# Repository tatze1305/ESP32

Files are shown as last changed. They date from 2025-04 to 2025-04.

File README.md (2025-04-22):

# ESP32 Entwicklerboard — KiCad Projekt 🕸️

Dies ist das Open-Source-Projekt **Spinne Werkstatt**, erstellt mit [KiCad](https://kicad.org/).  
Es handelt sich um ein Platinen-Design, das frei zur Verfügung steht und für eigene Zwecke verwendet, modifiziert oder weitergegeben werden kann.

---

## 🔧 Inhalt

- `esp32.kicad_sch` — Schaltplan-Datei  
- `esp32.kicad_pcb` — Platinenlayout  
- `gerber/` — Produktionsdaten (Gerber Files)  
- `PDF/` — PDF-Exports für Dokumentation  
- `README.md` — Diese Datei  
- `LICENSE` — Lizenzinformationen (MIT License)

---

## 🚀 Verwendung

Du kannst dieses Projekt:
- verwenden,
- verändern,
- kommerziell oder privat vertreiben,
- als Basis für eigene Entwicklungen nutzen.

Bitte beachte die Lizenzbedingungen in der `LICENSE`-Datei.

---

## 🧑‍💻 Mitmachen

Pull-Requests, Verbesserungen, Bug-Reports oder Ideen sind willkommen!  
Einfach ein Issue öffnen oder forken und loslegen.

---

## 📄 Lizenz

Dieses Projekt steht unter der [MIT License](LICENSE).

> Frei zur Nutzung, Veränderung und Verbreitung — mit Namensnennung.

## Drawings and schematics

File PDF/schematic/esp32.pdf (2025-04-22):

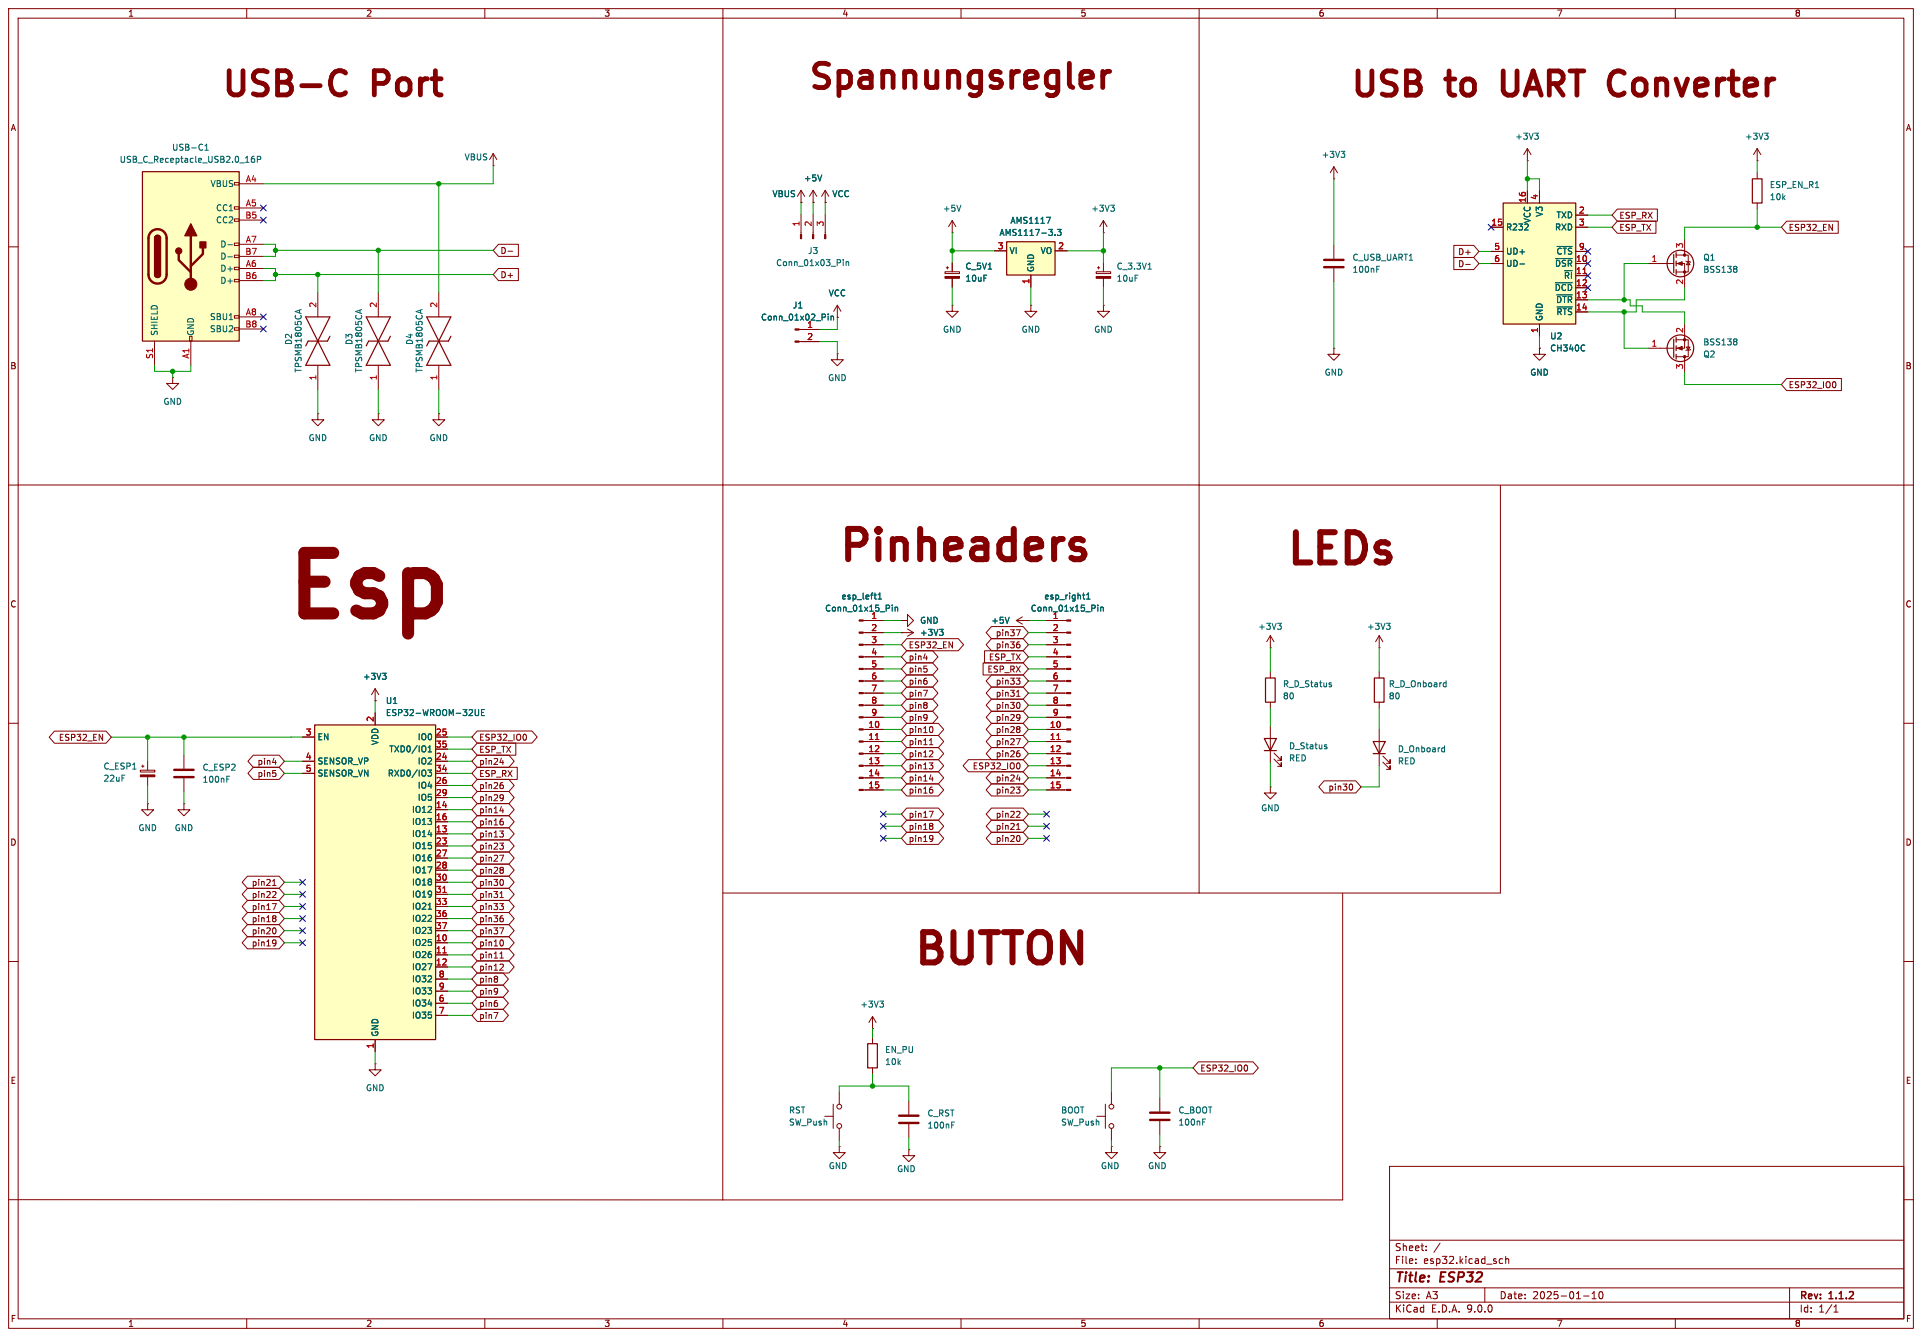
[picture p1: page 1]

1 2 D2 TPSMB1805CA GND SHIELD S1 GND A1 VBUS A4 CC1 A5 CC2 B5 D- A7 D- B7 D+ A6 D+ B6 SBU1 A8 SBU2 B8 USB-C1 USB_C_Receptacle_USB2.0_16P GND

1 TXD 2 RXD 3 ~{CTS}9 ~{DSR} 10 ~{RI} 11 ~{DCD} 12 ~{DTR} 13 ~{RTS} 14 U2 CH340C

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

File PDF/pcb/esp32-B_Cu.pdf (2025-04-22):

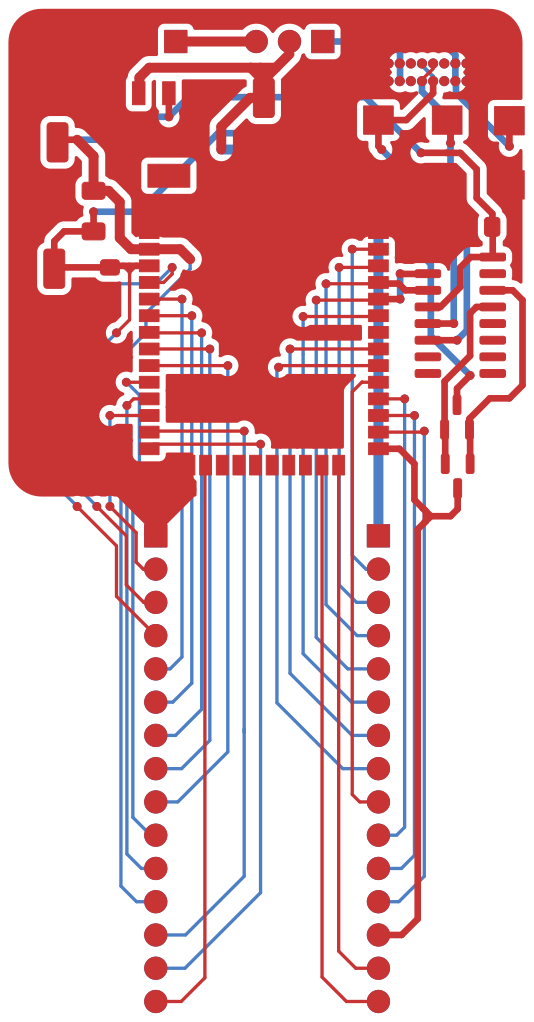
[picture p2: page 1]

Id: 2/4 Title: File: esp32.kicad_pcb Sheet:

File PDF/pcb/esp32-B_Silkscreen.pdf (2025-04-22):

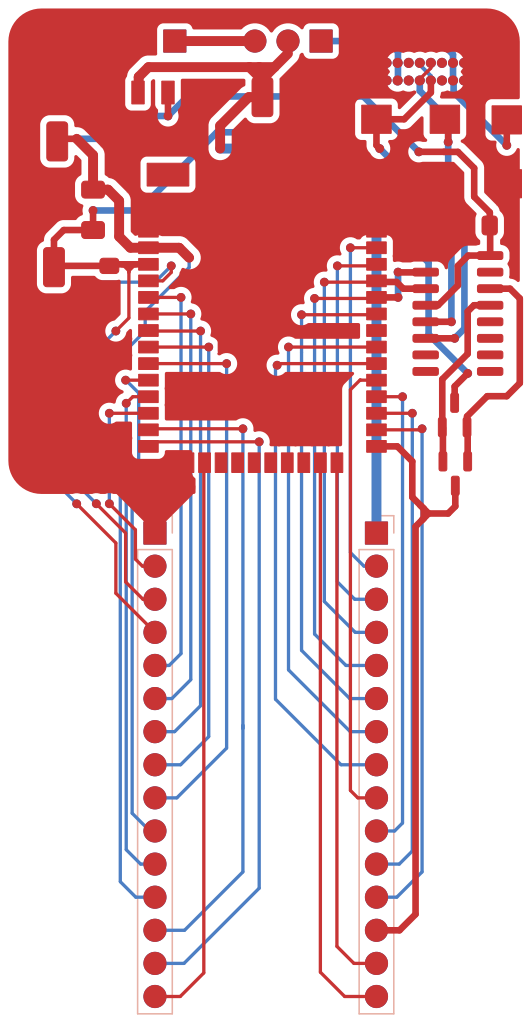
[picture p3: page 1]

Id: 4/4 Title: File: esp32.kicad_pcb Sheet:

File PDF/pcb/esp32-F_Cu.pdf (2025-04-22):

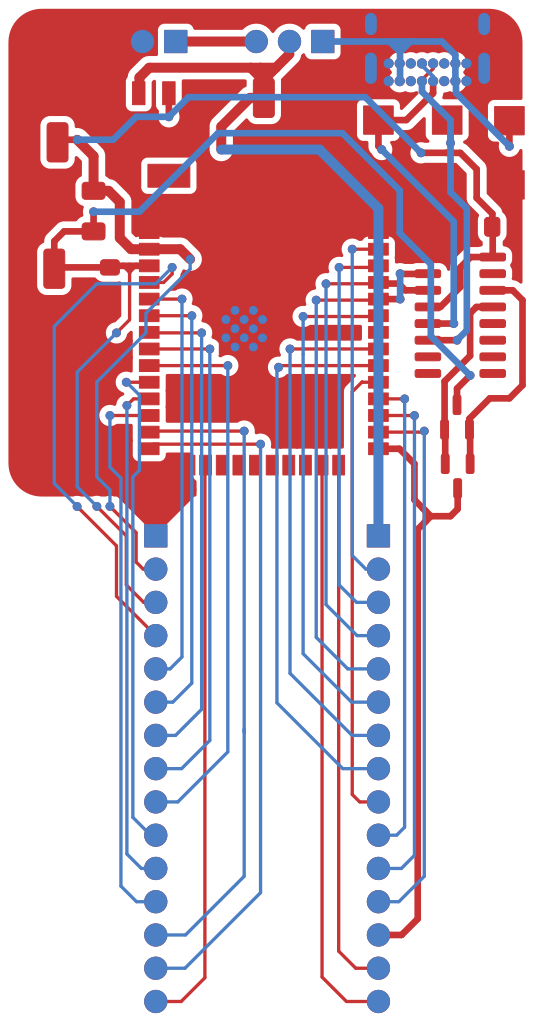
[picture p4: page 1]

Id: 1/4 Title: File: esp32.kicad_pcb Sheet:

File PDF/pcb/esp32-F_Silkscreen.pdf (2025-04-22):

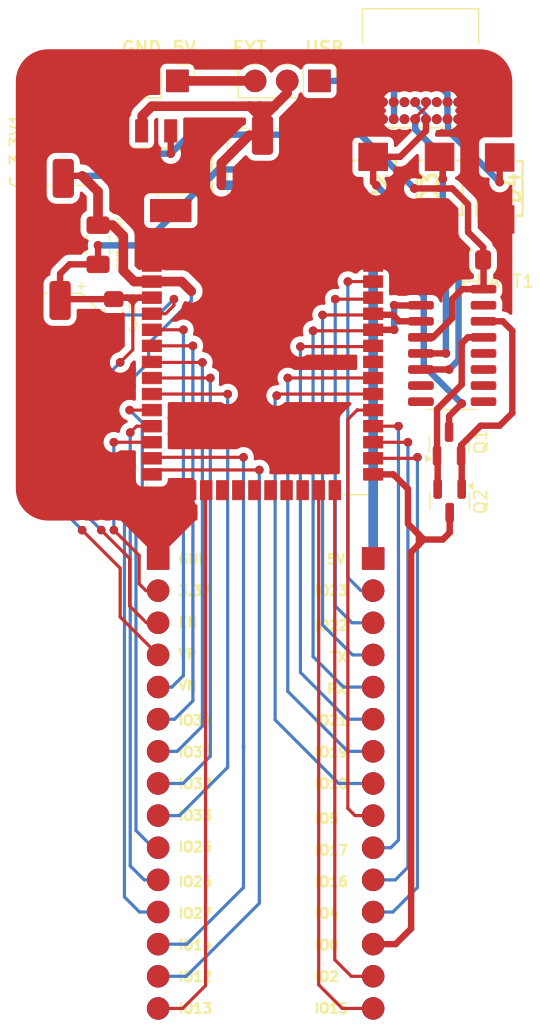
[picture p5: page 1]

Id: 3/4 Title: File: esp32.kicad_pcb Sheet:

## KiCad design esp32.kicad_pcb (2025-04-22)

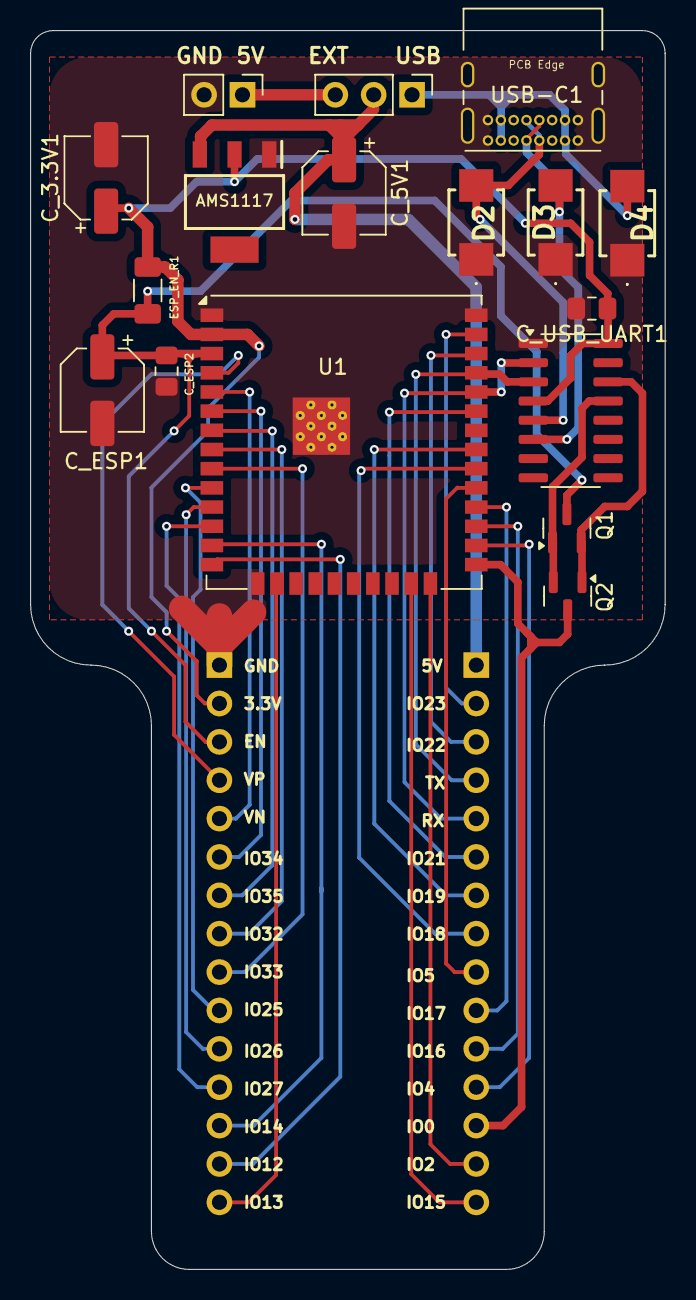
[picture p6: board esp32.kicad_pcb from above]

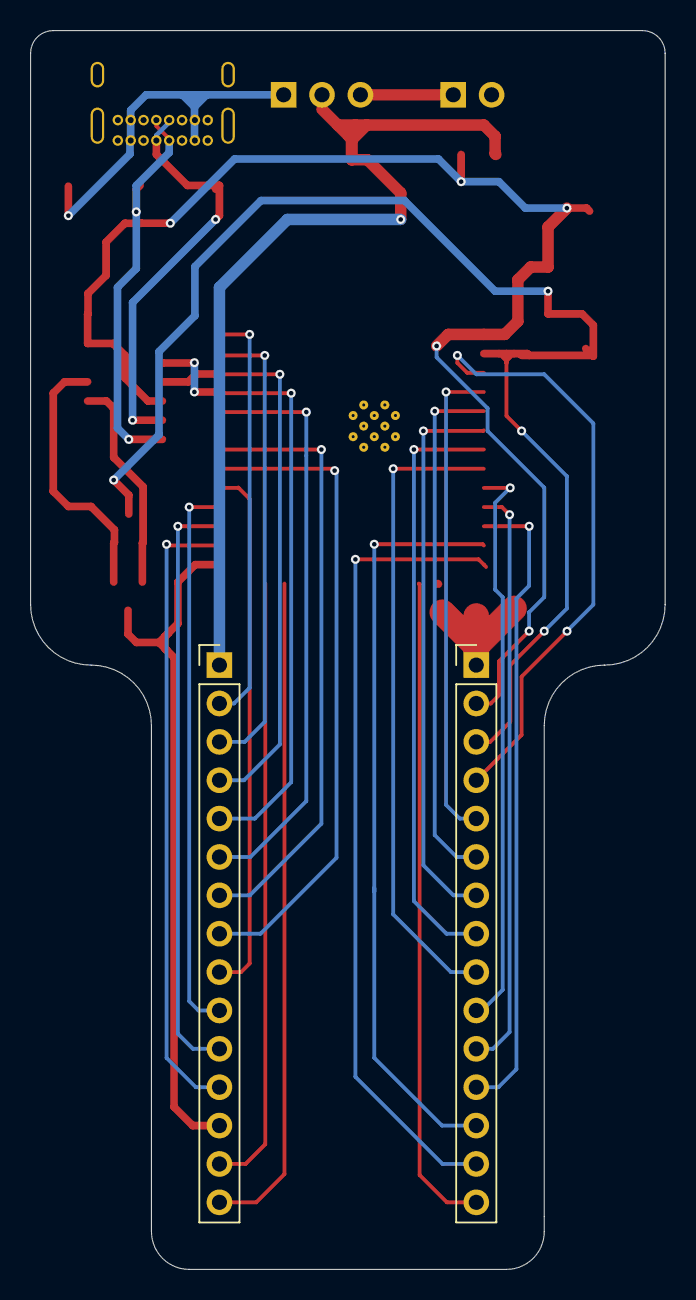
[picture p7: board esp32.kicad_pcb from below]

Board: 2 copper layers, 42.0 x 82.0 mm, 19 parts (2 on the bottom side), 36 nets.

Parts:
AMS1117: AMS1117-3.3; SOT230P700X180-4N
C_3.3V1, C_5V1: 1uF; CP_Elec_5x5.4
C_ESP1: 22uF; CP_Elec_5x5.4
C_ESP2: 100nF; C_0805_2012Metric_Pad1.18x1.45mm_HandSolder
C_USB_UART1: 100nF; C_0805_2012Metric_Pad1.18x1.45mm_HandSolder
D2, D3, D4: TPSMB1805CA
ESP_EN_R1: 10k; R_1206_3216Metric_Pad1.30x1.75mm_HandSolder
J1: Conn_01x02_Pin; PinHeader_1x02_P2.54mm_Vertical
J3: Conn_01x03_Pin; PinHeader_1x03_P2.54mm_Vertical
Q1, Q2: BSS138; SOT-23
U1: ESP32-WROOM-32UE
U2: CH340C; SOIC-16_3.9x9.9mm_P1.27mm
USB-C1: USB_C_Receptacle_USB2.0_16P; USB_C_Receptacle_GCT_USB4085
esp_left1: Conn_01x15_Pin; PinHeader_1x15_P2.54mm_Vertical
esp_right1: Conn_01x15_Pin; PinHeader_1x15_P2.54mm_Vertical

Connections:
+3V3: AMS1117.2 (VO), C_3.3V1.1, C_USB_UART1.1, ESP_EN_R1.1, U1.2 (VDD), U2.4 (V3), U2.16 (VCC), esp_left1.2
+5V: AMS1117.3 (VI), C_5V1.1, J3.2, esp_right1.1
D+: D2.2, U2.5 (UD+), USB-C1.A6 (D+), USB-C1.B6 (D+)
D-: D3.2, U2.6 (UD-), USB-C1.A7 (D-), USB-C1.B7 (D-)
ESP32_EN: C_ESP1.1, C_ESP2.1, ESP_EN_R1.2, Q1.3 (D), U1.3 (EN), esp_left1.3
ESP32_IO0: Q2.3 (D), U1.25 (IO0), esp_right1.13
ESP_RX: U1.34 (RXD0/IO3), U2.2 (TXD), esp_right1.5
ESP_TX: U1.35 (TXD0/IO1), U2.3 (RXD), esp_right1.4
GND: AMS1117.1 (GND), C_3.3V1.2, C_5V1.2, C_ESP1.2, C_ESP2.2, C_USB_UART1.2, D2.1, D3.1, D4.1, J1.2, U1.1 (GND), U1.15 (GND), U1.38 (GND), U1.39 (GND), U2.1 (GND), USB-C1.A1 (GND), USB-C1.A12 (GND), USB-C1.B1 (GND), USB-C1.B12 (GND), USB-C1.S1 (SHIELD), esp_left1.1
unnamed: Q1.1 (G), Q2.2 (S), U2.13 (~DTR)
unnamed: Q1.2 (S), Q2.1 (G), U2.14 (~RTS)
VBUS: D4.2, J3.1, USB-C1.A4 (VBUS), USB-C1.A9 (VBUS), USB-C1.B4 (VBUS), USB-C1.B9 (VBUS)
VCC: J1.1, J3.3
pin4: U1.4 (SENSOR_VP), esp_left1.4
pin5: U1.5 (SENSOR_VN), esp_left1.5
pin6: U1.6 (IO34), esp_left1.6
pin7: U1.7 (IO35), esp_left1.7
pin8: U1.8 (IO32), esp_left1.8
pin9: U1.9 (IO33), esp_left1.9
pin10: U1.10 (IO25), esp_left1.10
pin11: U1.11 (IO26), esp_left1.11
pin12: U1.12 (IO27), esp_left1.12
pin13: U1.13 (IO14), esp_left1.13
pin14: U1.14 (IO12), esp_left1.14
pin16: U1.16 (IO13), esp_left1.15
pin23: U1.23 (IO15), esp_right1.15
pin24: U1.24 (IO2), esp_right1.14
pin26: U1.26 (IO4), esp_right1.12
pin27: U1.27 (IO16), esp_right1.11
pin28: U1.28 (IO17), esp_right1.10
pin29: U1.29 (IO5), esp_right1.9
pin30: U1.30 (IO18), esp_right1.8
pin31: U1.31 (IO19), esp_right1.7
pin33: U1.33 (IO21), esp_right1.6
pin36: U1.36 (IO22), esp_right1.3
pin37: U1.37 (IO23), esp_right1.2

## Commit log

2024-12-12 add esp32 wroom
    [Spinne_Werkstatt.csv, Spinne_Werkstatt.kicad_pcb, Spinne_Werkstatt.kicad_sch]
2024-12-12 added esp32 wroom 32UE
    [Spinne_Werkstatt.kicad_sch]
2024-12-13 finished first pcb -- ugly
    [Spinne_Werkstatt.kicad_pcb]
2024-12-30 nearly finished, not perfect but ok
    [Spinne_Werkstatt.kicad_pcb]
2024-12-30 finished, not that bad
    [Spinne_Werkstatt.kicad_pcb]
2024-12-30 removed errors, only esp gnd and usb c port ramaining errors, not fixable
    [Spinne_Werkstatt.kicad_pcb]
2024-12-30 added gerber files
    [Spinne_Werkstatt-B_Cu.gbr, Spinne_Werkstatt-B_Mask.gbr, Spinne_Werkstatt-B_Paste.gbr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]
2024-12-30 added gerber
    [Spinne_Werkstatt-B_Cu.gbl, Spinne_Werkstatt-B_Cu.gbr, Spinne_Werkstatt-B_Mask.gbr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]
2024-12-30 finished gerber issue
    [Spinne_Werkstatt.kicad_pcb]
2024-12-31 improved ground plain -- version 1.1.2
    [Spinne_Werkstatt.kicad_pcb]
2024-12-31 renewed zip
    [Spinne_Werkstatt-B_Cu.gbl, Spinne_Werkstatt-B_Mask.gbs, Spinne_Werkstatt-B_Paste.gbp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]
2024-12-31 added IO Names, improved vias
    [Spinne_Werkstatt-B_Cu.gbl, Spinne_Werkstatt-B_Mask.gbs, Spinne_Werkstatt-B_Paste.gbp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]
2024-12-31 improved clearences around uart capacitor
    [Spinne_Werkstatt.kicad_pcb]
2024-12-31 improved clearence around uart capacitor
    [Spinne_Werkstatt-B_Cu.gbl, Spinne_Werkstatt-B_Mask.gbs, Spinne_Werkstatt-B_Paste.gbp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]
2024-12-31 changed elko footprints, changed voltage regulator footprint
    [Spinne_Werkstatt-B_Cu.gbl, Spinne_Werkstatt-B_Mask.gbs, Spinne_Werkstatt-B_Paste.gbp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]
2024-12-31 finished footprints, all completed -- version 1.1.2
    [Spinne_Werkstatt-B_Cu.gbl, Spinne_Werkstatt-B_Mask.gbs, Spinne_Werkstatt-B_Paste.gbp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]
2025-01-01 placed names on silkscreen better
    [Spinne_Werkstatt-B_Cu.gbl, Spinne_Werkstatt-B_Mask.gbs, Spinne_Werkstatt-B_Paste.gbp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]
2025-01-01 improved names on silkscreen x2
    [Spinne_Werkstatt-B_Cu.gbl, Spinne_Werkstatt-B_Mask.gbs, Spinne_Werkstatt-B_Paste.gbp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]
2025-01-01 added additional USB data protection, not pretty -- version 1.1.3
    [Spinne_Werkstatt-B_Cu.gbl, Spinne_Werkstatt-B_Mask.gbs, Spinne_Werkstatt-B_Paste.gbp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]
2025-01-03 elias stinkt
    [Spinne_Werkstatt.kicad_pcb, Spinne_Werkstatt.kicad_sch]
2025-01-10 changed ch340c cap to 0805
    [Spinne_Werkstatt-B_Cu.gbl, Spinne_Werkstatt-B_Mask.gbs, Spinne_Werkstatt-B_Paste.gbp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]
2025-01-10 added schematic pdf
2025-01-11 removed usb data protection ic, improvements -- version 1.1.4
    [Spinne_Werkstatt.kicad_pcb, Spinne_Werkstatt.kicad_sch]
2025-04-22 Clean: remove now-ignored KiCad temp files
2025-04-22 Improved Gitignore
    [Spinne_Werkstatt.csv]
2025-04-22 added pdfs for pcb and schematic --> /PDF, and removed something in .gitignore
    [Spinne_Werkstatt.kicad_pcb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]
2025-04-22 Added Readme and License
    [Spinne_Werkstatt.kicad_pcb]
2025-04-22 Renamed everything
    [Spinne_Werkstatt-B_Cu.gbl, Spinne_Werkstatt-B_Mask.gbs, Spinne_Werkstatt-B_Paste.gbp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]
2025-05-05 removed c at processor
    [esp32.kicad_sch]
